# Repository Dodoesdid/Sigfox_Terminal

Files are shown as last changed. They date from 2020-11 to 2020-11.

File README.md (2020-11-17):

# Sigfox Terminal

## Overview
This is collaboration done by four students in NTUST. Anshul and Pratik are PhD students from ME, Quency and Jonathan are undergraduate students from ECE. This projects aims at making a low power Sigfox terminal device.

## Features
* 2 year long battery life
* Notifications through Sigfox in case of a peripheral update

## Specifications
1. MCU: stm32f103c8t6 
2. Sigfox Transciever: UnaMkr Mini
3. PCB: 4 layered
4. Components: SMD 0805 to 2010

## Design Environment
* Embedded C: KeilARM
* PCB: EasyPC
> Note: These two IDEs are both free with limited access

## File Structure
```C
+---C
|   +---Drivers             // drivers provided by ARM and ST
|   |   +---CMSIS
|   |   +---STM32F1xx_HAL_Driver
|   \---Inc
|   \---MDK-ARM
|   \---Src                 // User code
\---PCB
    +---Design_1            // First Design using DIP components   
    \---Design_2            // Second Design using SMD components
        |   Project_2.sch   // Schematic file
        |   Project_2_1.pcb // PCB file
        \---Outputs
            +---BOM         // Bill of Material (Component List)
            +---Gerber      // File for PCB Manufacturer
            \---Schematic   // PDF schematics for reading purpose
```
## Final Product

### Device

### Sigfox Backend


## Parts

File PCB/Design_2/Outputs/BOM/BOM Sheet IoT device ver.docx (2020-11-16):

BOM Sheet IoT device ver. 2

NTUST ME : Anshul Pratik NTUST ECE: Jonathan Quency 2020/5/5

1. Transceiver: Una MKR mini

Distributer: IC shop Price: 819NT

2. Antenna: Any Sigfox compatible antenna

Distributer: IC shop Price: 250NT

3. PCB: 4 layer, 10cm*6cm

Distributer: Jiepei (China) Price: 120NT

4. Components

Distributer: Price: 200NT

Component | Packaging | Value | Qty | Remarks
C | 0805 | 15p | 1
C | 0805 | 20p | 2
C | 0805 | 100n | 9
C | 0805 | 220n | 1
C | 2010 | 1u | 2 | Tantalum capacitor
C | 2010 | 10u | 4 | Tantalum capacitor
L | 1206 | 1u | 1
LED | 0805 | | 1
R | 1206 | 1k | 1
R | 1206 | 1M | 1 | 5% or lower
R | 1206 | 10k | 3 | 5% or lower
R | 1206 | 150 | 2 | 5% or lower
R | 1206 | 200k | 1 | 0.5% or lower
R | 1206 | 510 | 1 | 5% or lower
R | 1206 | 3.3k | 2 | 5% or lower
R | 1206 | 30m | 1 | 1% or lower 30m-50m ok
Oscillator | HC-49S | 8M | 1
Oscillator | Cylindrical | 32.768k | 1 | 1 mil footprint
2pin connector | JST PH2.0 2P | | 7 | male
2pin connector | JST PH2.0 2P | | 7 | female
Screw | M3 | | 8 | For housing
CR123A | | 1200mAh | 2 | Battery
Bat. Case | | | 2
STC3100 | | | 1 | Battery detection chip
Stm32f103c8t6 | | | 1 | MCU

Total Price per device: 1389NT

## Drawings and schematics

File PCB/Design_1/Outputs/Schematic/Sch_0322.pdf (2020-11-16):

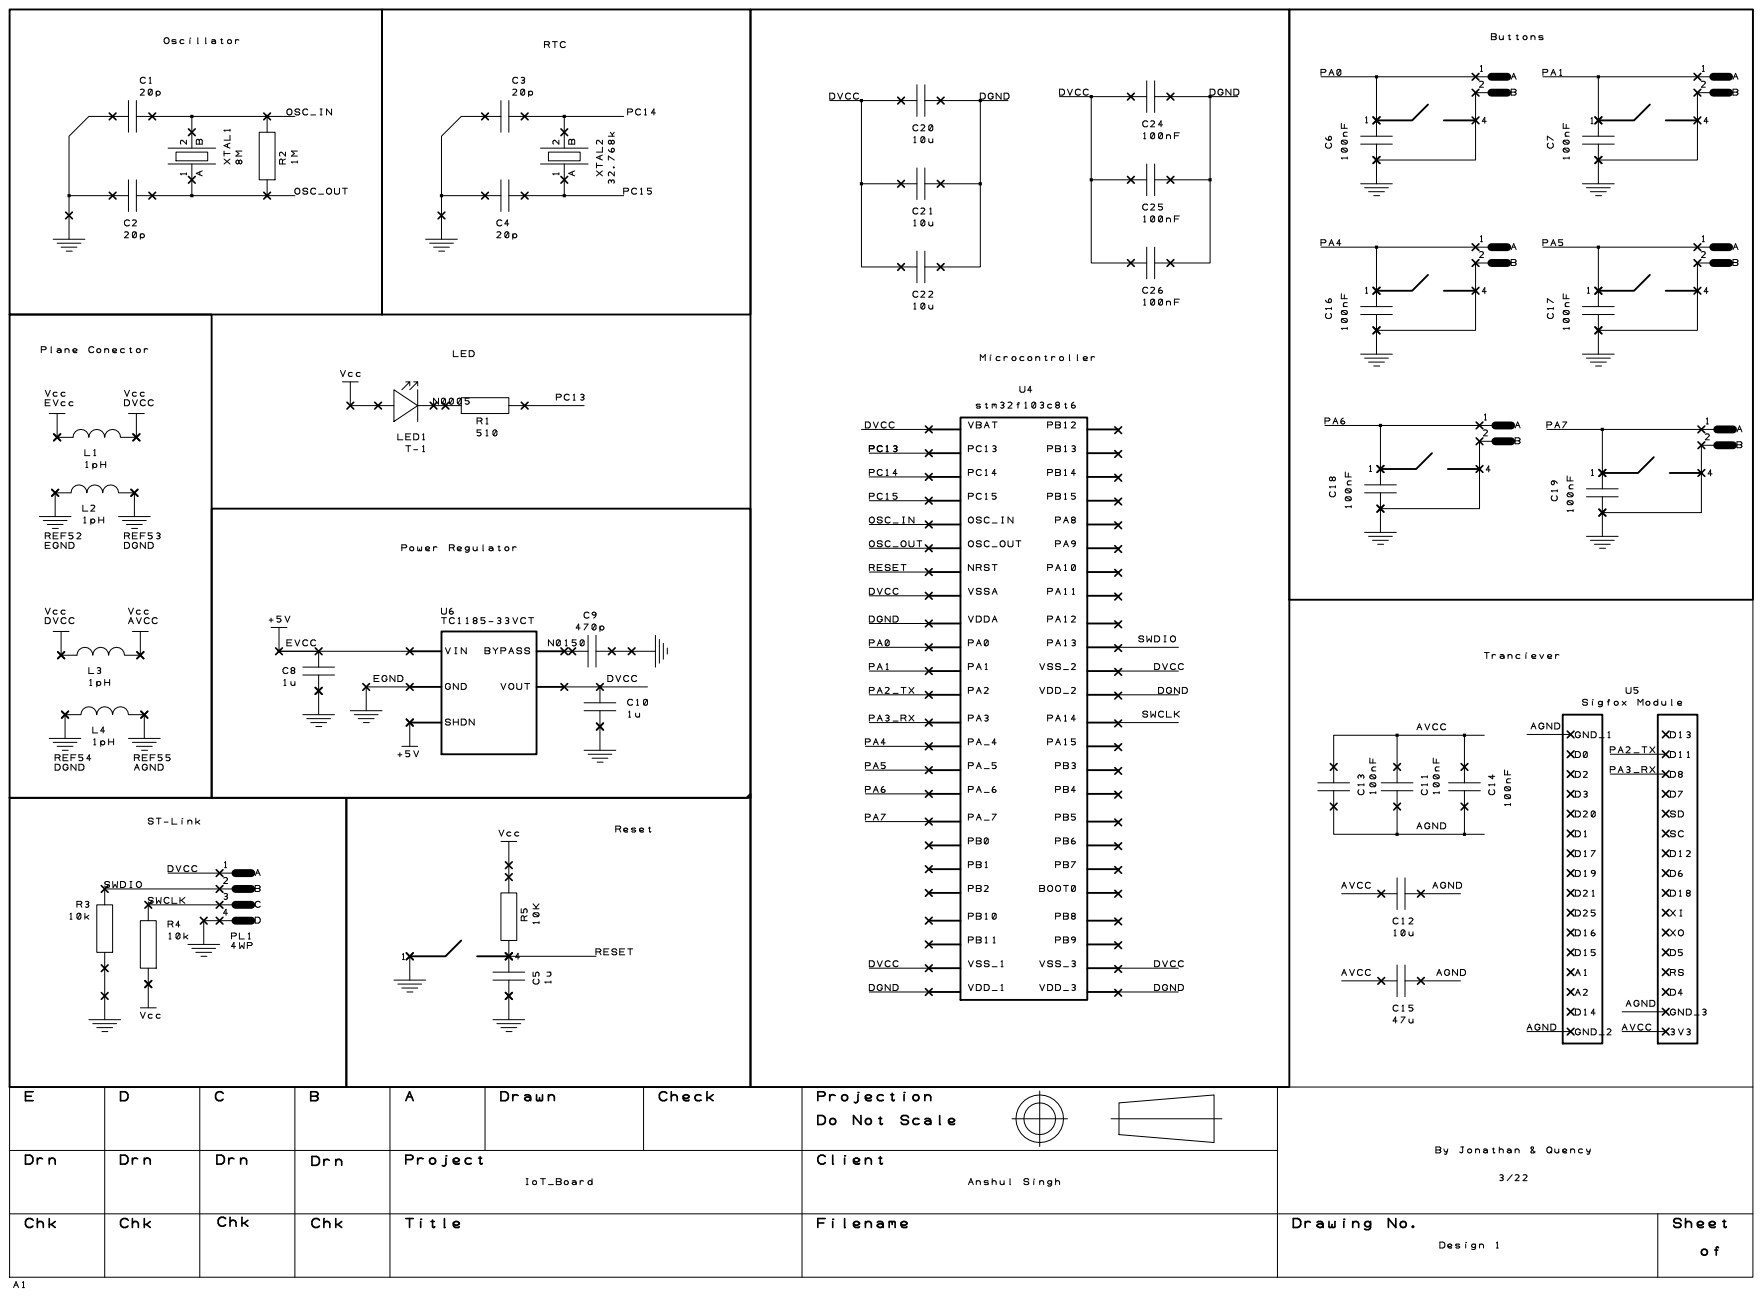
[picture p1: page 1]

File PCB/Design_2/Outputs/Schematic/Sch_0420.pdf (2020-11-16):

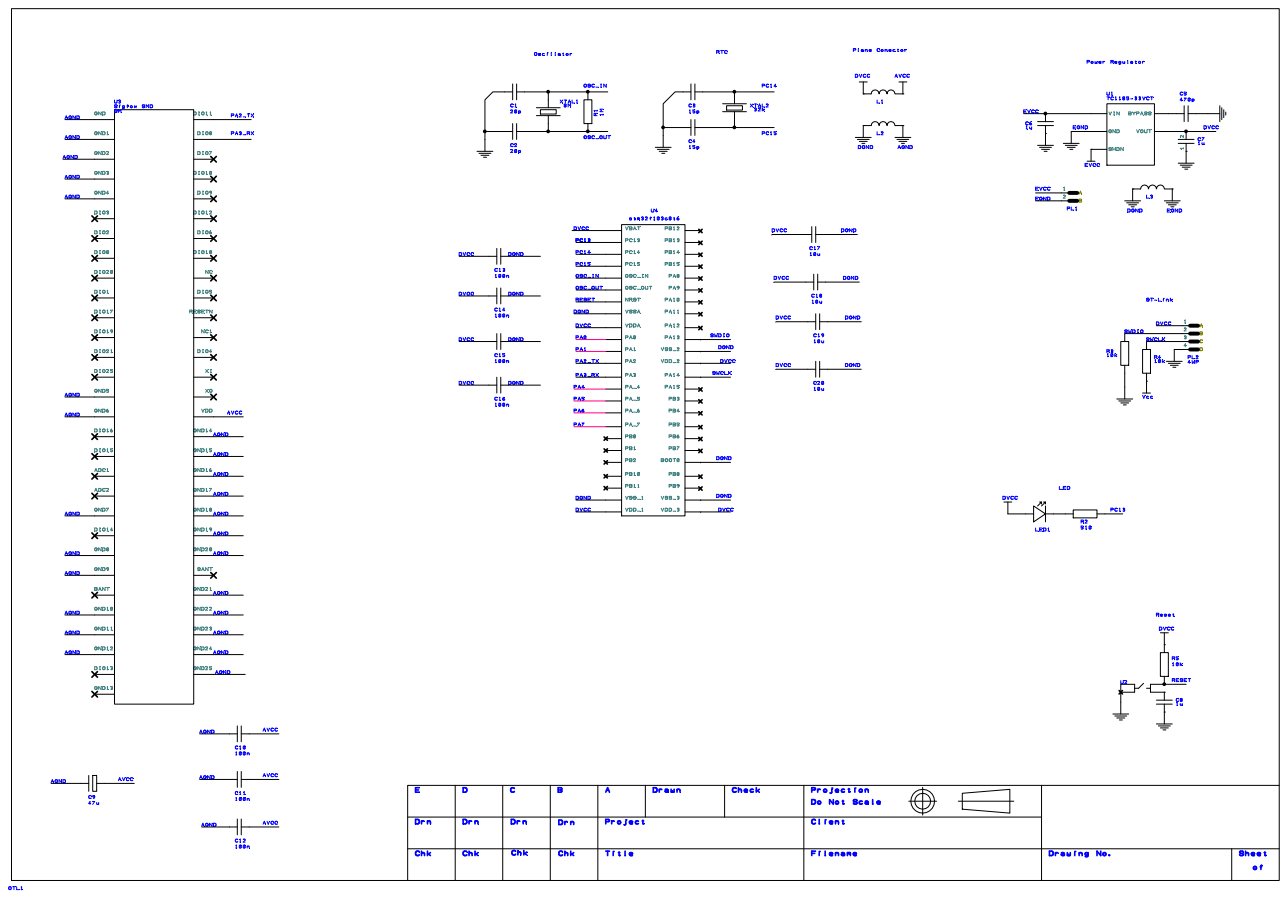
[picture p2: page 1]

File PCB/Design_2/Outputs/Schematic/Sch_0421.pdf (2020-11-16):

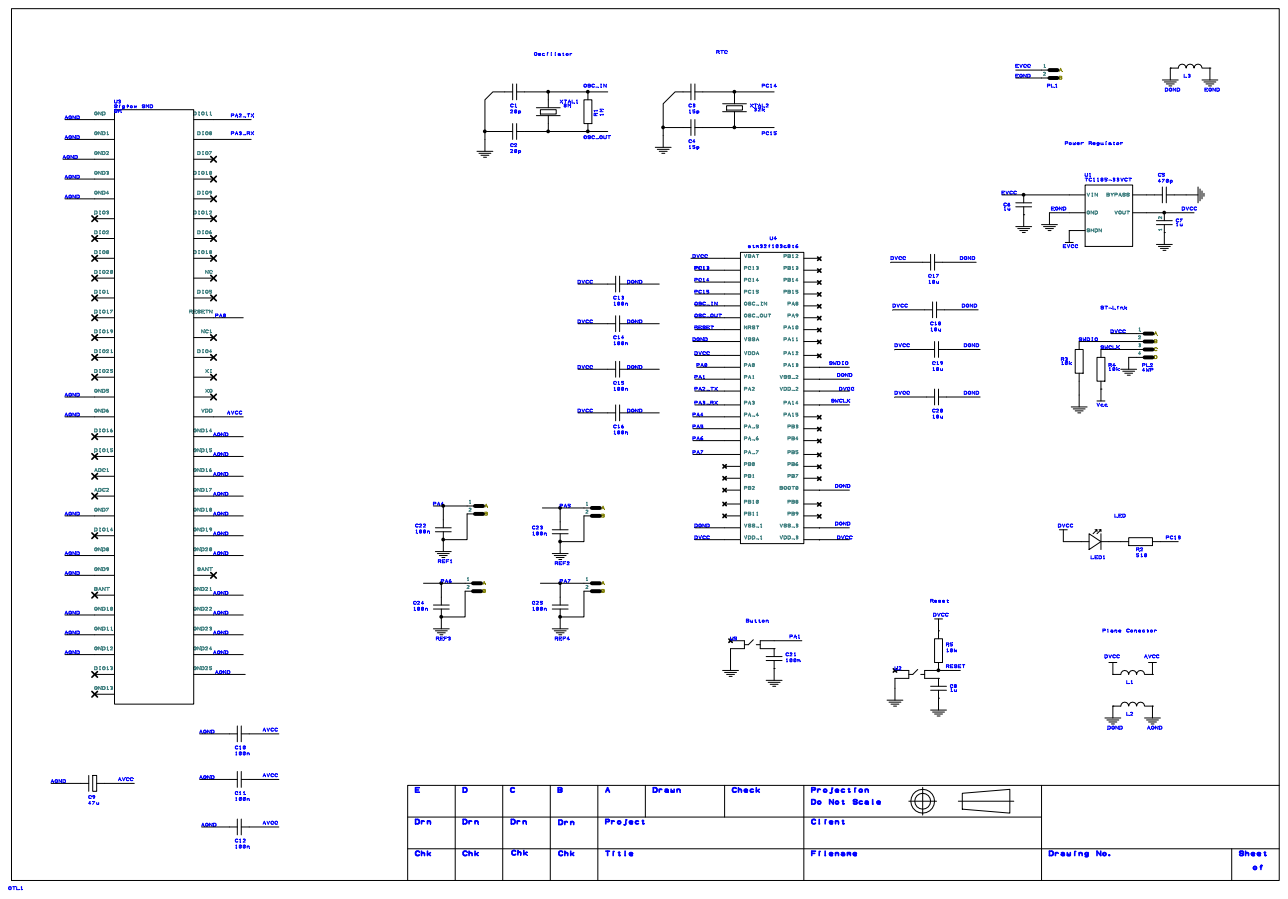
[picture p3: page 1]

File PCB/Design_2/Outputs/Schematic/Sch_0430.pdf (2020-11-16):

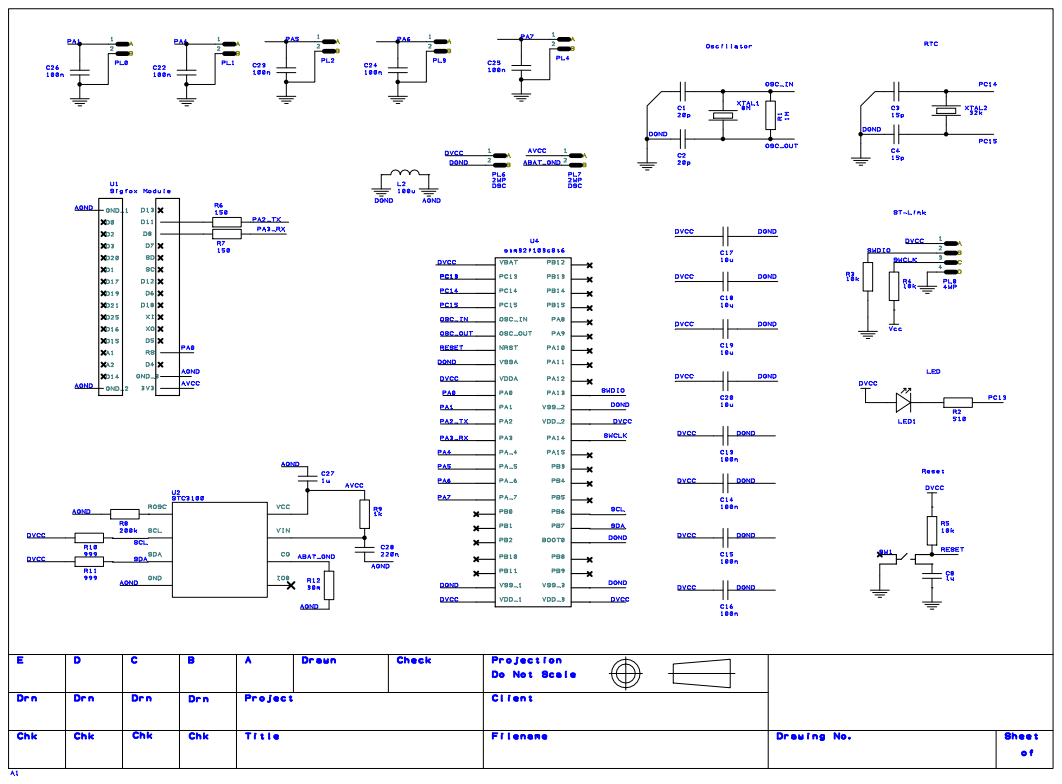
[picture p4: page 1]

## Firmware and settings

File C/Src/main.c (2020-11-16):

/**
  ******************************************************************************
  * @file           : main.c
  * @brief          : Main program body
  ******************************************************************************
  ** This notice applies to any and all portions of this file
  * that are not between comment pairs USER CODE BEGIN and
  * USER CODE END. Other portions of this file, whether 
  * inserted by the user or by software development tools
  * are owned by their respective copyright owners.
  *
  * COPYRIGHT(c) 2020 STMicroelectronics
  *
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
  ******************************************************************************
  */
/* Includes ------------------------------------------------------------------*/
#include "main.h"
#include "stm32f1xx_hal.h"

/* USER CODE BEGIN Includes */
/**
  @brief PA3:USART2_Rx
         PA2:USART2_Tx
         PA0:SIGFOX_NRST, output
         PA1:EXTI1, falling, internal pull-up
         PA4:EXTI4, falling, internal pull-up
         PA5:EXTI5, falling, internal pull-up
         PA6:EXTI6, falling, internal pull-up
         PA7:EXTI7, falling, internal pull-up
         
         If internal 40kHz is used for RTC,
         then hrtc.Init.AsynchPrediv should be callibrated instead of RTC_AUTO_1_SECOND
         because internal RC 40kHz is not accurate.
*/
#define SKIP_OK 0 //if==1, then not waiting for OK response.
/* USER CODE END Includes */

I2C_HandleTypeDef hi2c1;

RTC_HandleTypeDef hrtc;

UART_HandleTypeDef huart2;
DMA_HandleTypeDef hdma_usart2_rx;

/* USER CODE BEGIN PV */

/** @brief using printf() as HAL_UART_Transmit() */
#ifdef __GNUC__
/* With GCC/RAISONANCE, small printf (option LD Linker->Libraries->Small printf
 set to 'Yes') calls __io_putchar() */
  #define PUTCHAR_PROTOTYPE int __io_putchar(int ch)
#else
  #define PUTCHAR_PROTOTYPE int fputc(int ch, FILE *f)
#endif /* __GNUC__ */
PUTCHAR_PROTOTYPE{
 /* Place your implementation of fputc here */
 /* e.g. write a character to the USART1 and Loop until the end of transmission */
  HAL_UART_Transmit(&huart2, (uint8_t *)&ch, 1, 0xFF);
//HAL_UART_Transmit(UART_HandleTypeDef* huart, uint8_t pData, uint16_t Size, uint32_t Timeout);
  return ch;
}

/* USER CODE END PV */

void SystemClock_Config(void);
static void MX_GPIO_Init(void);
static void MX_DMA_Init(void);
static void MX_USART2_UART_Init(void);
static void MX_RTC_Init(void);
static void MX_I2C1_Init(void);

/* USER CODE BEGIN PFP */
void alarm_set_init(void);
int8_t tran_ATCMD(const char* CMD, uint16_t timeout);
int8_t get_PVD(void);
/* USER CODE END PFP */

/* USER CODE BEGIN 0 */
char* ATCMD_PING      = ATCMD_PING_LIT     ;
char* ATCMD_SLEEP     = ATCMD_SLEEP_LIT    ;
char* ATCMD_BAT_OK    = ATCMD_BAT_OK_LIT   ;
char* ATCMD_BAT_LOW   = ATCMD_BAT_LOW_LIT  ;
char* ATCMD_PA1_EXTI1 = ATCMD_PA1_EXTI1_LIT;
char* ATCMD_PA4_EXTI4 = ATCMD_PA4_EXTI4_LIT;
char* ATCMD_PA5_EXTI5 = ATCMD_PA5_EXTI5_LIT;
char* ATCMD_PA6_EXTI6 = ATCMD_PA6_EXTI6_LIT;  //_LIT stands for literal.
char* ATCMD_PA7_EXTI7 = ATCMD_PA7_EXTI7_LIT;  //ATCMD_XXX_LIT defined in main.h
/* USER CODE END 0 */

/**
  * @brief  The application entry point.
  *
  * @retval None
  */
int main(void)
{
  /* MCU Configuration----------------------------------------------------------*/

  /* Reset of all peripherals, Initializes the Flash interface and the Systick. */
  HAL_Init();

  /* Configure the system clock */
  SystemClock_Config();

  /* Initialize all configured peripherals */
  MX_GPIO_Init();
  MX_DMA_Init();
  MX_USART2_UART_Init();
  MX_RTC_Init();
  MX_I2C1_Init();
  /* Infinite loop */
  /* USER CODE BEGIN WHILE */
  HAL_GPIO_WritePin(GPIOC, GPIO_PIN_13, LED_ON);
  
  //without this delay, uart may not work with VDD rising from 1.1V to 3.3V fast
  HAL_Delay(1000);//connector bouncing when connecting causes unstable VDD
  tran_ATCMD(ATCMD_PING, ATCMD_TO_GEN);
  tran_ATCMD(ATCMD_SLEEP, ATCMD_TO_GEN);
  alarm_set_init();
  HAL_GPIO_WritePin(GPIOC, GPIO_PIN_13, LED_OFF);
  HAL_PWR_EnterSTOPMode(PWR_LOWPOWERREGULATOR_ON, PWR_STOPENTRY_WFI);//WFI:wait for interrupt
  while (1)
  {
  /* USER CODE END WHILE */

  /* USER CODE BEGIN 3 */
  }
  /* USER CODE END 3 */

}

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
/* USER CODE BEGIN 4 */
void alarm_set_init(){
  RTC_AlarmTypeDef alarm;
  alarm.AlarmTime.Hours=0;
  alarm.AlarmTime.Minutes=1;
  alarm.AlarmTime.Seconds=0;
  alarm.Alarm=RTC_ALARM_A; //only 1 alarm available for stm32f103c8
  HAL_RTC_SetAlarm_IT(&hrtc, &alarm, RTC_FORMAT_BIN);
}

/**
  * @brief  Polling PVD from threhold level 0 to 7.
  * @retval return 0~7, corespongind VDD is lower than which level. 
  *         return -1 if VDD is higher than every level.
  */
int8_t get_PVD(){
  PWR_PVDTypeDef pvd;
  for(uint8_t lv=0; lv<=7; lv++){
      HAL_Delay(30);
      pvd.Mode=PWR_PVD_MODE_IT_RISING;
      pvd.PVDLevel=lv<<5; //5 is register shift of PLS[2:0] in PWR->CR.
      HAL_PWR_ConfigPVD(&pvd);
      HAL_PWR_EnablePVD();
      if(PWR->CSR&1U<<2) //PWR->CSR[2] is PVD Output. PVDO==1 when VDD is lower, vise versa.
        return lv;
  }
  return -1;  //return -1 if VDD is higher then threshold level 7.
}

/**
  * @brief  Transimit AT command and poll for OK response before timeout.
  * @param  cmd: the AT command to transmit.
  * @param  timeOut: duration polling for OK response, in millisecond.
  * @retval return 0 if OK response detected.
  *         return -1 if no OK response detected.
  * @notes  If timeout then reset sigfox module.
  */
int8_t tran_ATCMD(const char* cmd, uint16_t timeOut){
#if SKIP_OK
  printf("Hi\r\n");
  HAL_Delay(100);
  printf("%s", cmd);
  return 0;
#else
  uint8_t text[30]={'\0'}; //buffer for storing AT response.
  uint32_t preTick;
  if(cmd == ATCMD_PING){ //if trying to wake up sigfox
    printf("a");  //sigfox module wakes up on any of its RX data.
    HAL_Delay(300);
    printf("Hi\r\n");
    HAL_Delay(200);
  }
  do{ //clear receiving buffer
    text[0]='\0';
    HAL_UART_Receive(&huart2, &(text[0]), 1, 0xF); //receive 1 byte from hardware buffer.
  }while(text[0]!='\0');
  HAL_UART_DMAStop(&huart2);
  HAL_UART_Receive_DMA(&huart2, text, 30);
  printf("%s", cmd);
  HAL_Delay(50);
  uint8_t i=0;
  int8_t isOK=-1;
  preTick=HAL_GetTick();
  while(HAL_GetTick()-preTick < timeOut && isOK==-1){ //break either timeout or OK detected
    i=0;
    while(text[i]!='\0' && i<29){ //check for response OK.
      if(text[i]=='O' && text[i+1]=='K'){
        isOK=1;
        break;
      }
      i++;
      HAL_Delay(10);
    }
  }
  HAL_UART_DMAStop(&huart2);
  if(isOK==-1){ //if not responding, then reset sigfox module.
    HAL_GPIO_WritePin(GPIOA, GPIO_PIN_0, RF_NRST_ON);
    HAL_Delay(200);
    HAL_GPIO_WritePin(GPIOA, GPIO_PIN_0, RF_NRST_OFF);
    HAL_Delay(3000);
  }
  return isOK; //return 0 if success
#endif
}
/* USER CODE END 4 */
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

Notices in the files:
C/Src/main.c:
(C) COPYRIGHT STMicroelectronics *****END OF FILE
